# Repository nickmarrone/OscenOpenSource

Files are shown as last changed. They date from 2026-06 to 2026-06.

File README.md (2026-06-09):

# Oscen Open Source

Open source hardware designs for **Oscen Eurorack Modules**.

This repository contains the KiCad design files (schematics, PCB layouts, panels)
and manufacturing outputs (Gerbers, BOMs, pick-and-place files) for a selection of
Oscen's Eurorack modules, released for the community to study, build, and remix.

## Modules

| Module | Format | Description |
| --- | --- | --- |
| [Quad Passive Switch](QuadPassiveSwitch/) | 4HP, 3U | Four independent SPDT passive switches for manually routing signals — no power required. |

### Quad Passive Switch

A 4HP utility module with four independent **SPDT (single-pole, double-throw)**
toggle switches. Each section takes one input and routes it to one of two outputs
(or, run in reverse, selects between two inputs feeding a single output). The
signal path is entirely passive, so the module needs no power and adds no coloration
— useful for routing audio, CV, gates, clocks, or triggers.

See the [module README](QuadPassiveSwitch/README.md) for full details.

## Repository layout

Each module lives in its own directory and contains:

- `*.kicad_sch` — schematic
- `*.kicad_pcb` — main PCB layout
- `*_faceplate.kicad_pcb` — panel / faceplate layout
- `*.kicad_pro` / `*.kicad_prl` — KiCad project files
- `*.pdf` — rendered schematic
- `production/` — Gerbers, drill files, BOM, and pick-and-place outputs ready for fabrication

## Building these modules

1. Open the module's `.kicad_pro` in [KiCad](https://www.kicad.org/) (8.0 or newer) to view or edit the design.
2. To fabricate, send the Gerber `.zip` files in the module's `production/` directory
   to a PCB manufacturer, along with the BOM (`*_bom.csv`) and position
   (`*_positions.csv`) files if you want assembly.

## License

These designs are released as open source hardware. Unless otherwise noted in a
module's directory, you are free to build, modify, and share them. Please credit
**Oscen Modules**.

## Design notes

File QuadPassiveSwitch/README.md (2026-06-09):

# Quad Passive Switch

A 4HP, 3U Eurorack utility module with four independent **SPDT** (single-pole,
double-throw) passive switches. Each section manually routes one signal between two
destinations using a sub-mini toggle switch. The whole module is passive — it needs
**no power** and adds no buffering or coloration to the signal.

## Specifications

| | |
| --- | --- |
| Format | Eurorack, 3U |
| Width | 4HP (20 mm) |
| Panel height | 128.5 mm |
| Depth | Shallow (passive, no power header) |
| Power | None required |
| Switches | 4 × SPDT sub-mini toggle |
| Jacks | 12 × 3.5 mm mono switched |

## How it works

The module is divided into four identical sections, arranged top-left (TL),
top-right (TR), bottom-left (BL), and bottom-right (BR). Each section has:

- **IN** — signal input
- **OUT 1** — output selected when the toggle is in position 1
- **OUT 2** — output selected when the toggle is in position 2

The toggle switch connects **IN** to either **OUT 1** or **OUT 2**. Because the
path is just a mechanical contact, it works with any signal: audio, CV, gates,
clocks, or triggers.

### Reverse use (2-to-1)

Since the switch is passive and symmetrical, each section can be used in reverse:
patch two sources into **OUT 1** and **OUT 2**, and the toggle selects which one
appears at **IN**. In this mode **IN** becomes the output and the OUTs become inputs.

> Note: as with any passive multiple/switch, only patch a signal into one side of a
> given section at a time when using it in reverse, to avoid summing or back-feeding
> sources.

## Bill of materials

| Designators | Qty | Part | Footprint |
| --- | --- | --- | --- |
| J1–J12 | 12 | 3.5 mm mono switched jack (PJ398SM) | `EighthInch_PJ398SM` |
| SW1–SW4 | 4 | SPDT sub-mini toggle | `Switch_Toggle_SPDT_SubMini` |

See [`production/quad_passive_switch_gerbers_v1.0_bom.csv`](production/quad_passive_switch_gerbers_v1.0_bom.csv)
for the fabrication BOM.

## Files

- `quad_passive_switch.kicad_sch` — schematic
- `quad_passive_switch.kicad_pcb` — main PCB layout
- `quad_passive_switch_faceplate.kicad_pcb` — panel / faceplate layout
- `quad_passive_switch.pdf` — rendered schematic
- `quad_passive_switch.kicad_pro` — KiCad project
- `production/` — Gerbers (`*_gerbers_v1.0.zip`, `*_faceplate_gerbers_v1.0.zip`),
  drill/netlist, BOM, designators, and pick-and-place position files for v1.0

## Building it

1. Open `quad_passive_switch.kicad_pro` in [KiCad](https://www.kicad.org/) 8.0+ to
   inspect or modify the design.
2. To fabricate, send `production/quad_passive_switch_gerbers_v1.0.zip` (PCB) and
   `production/quad_passive_switch_faceplate_gerbers_v1.0.zip` (panel) to a PCB
   manufacturer.
3. Solder the 12 jacks and 4 toggle switches per the BOM. There are no other
   components — no resistors, ICs, or power connector.

## Revision

- **v1.0** — initial release.

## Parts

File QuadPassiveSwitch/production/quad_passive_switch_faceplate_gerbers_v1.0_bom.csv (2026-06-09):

Designator | Footprint | Quantity | Value | LCSC Part #
J1, J10, J11, J12, J2, J3, J4, J5, J6, J7, J8, J9 | EighthInch_PJ398SM | 12 | 3.5mm_Mono_Switched_SymSmall_0.05
SW1, SW2, SW3, SW4 | Switch_Toggle_SPDT_SubMini | 4 | SW_SPDT_MSM

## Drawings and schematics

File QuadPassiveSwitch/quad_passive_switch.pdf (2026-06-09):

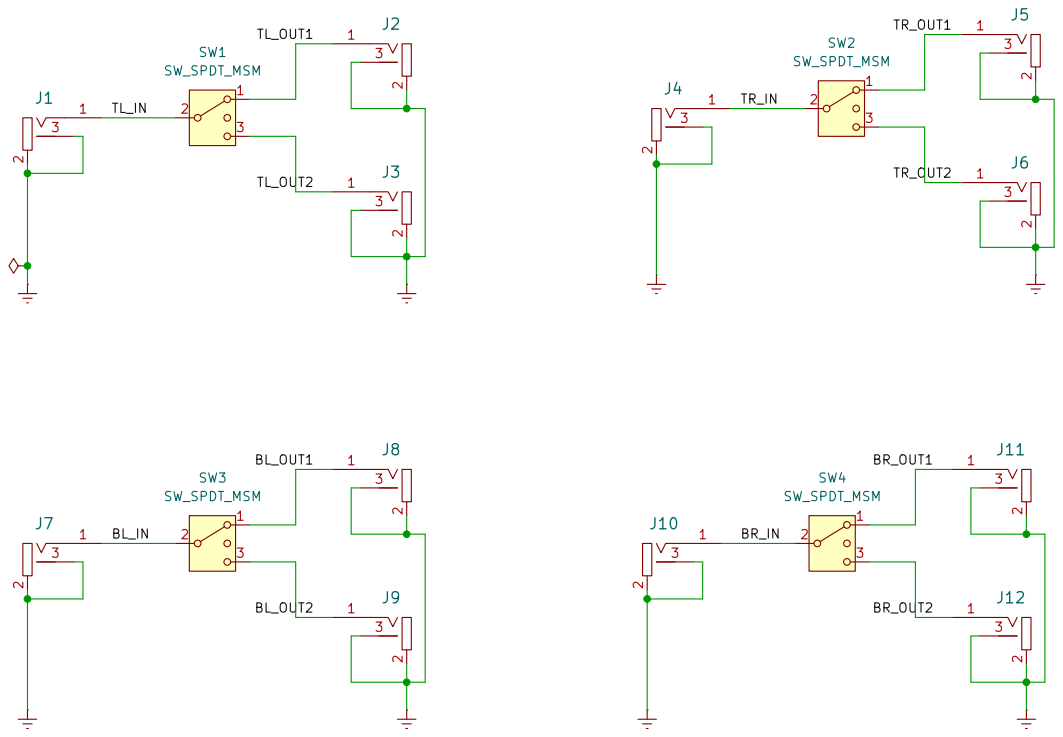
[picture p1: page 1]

Oscen Modules
Sheet: /
File: quad_passive_switch.kicad_sch
Title: Quad Passive Switch

Size: A4 | Rev: v1.0
KiCad E.D.A. 10.0.1 | Id: 1/1

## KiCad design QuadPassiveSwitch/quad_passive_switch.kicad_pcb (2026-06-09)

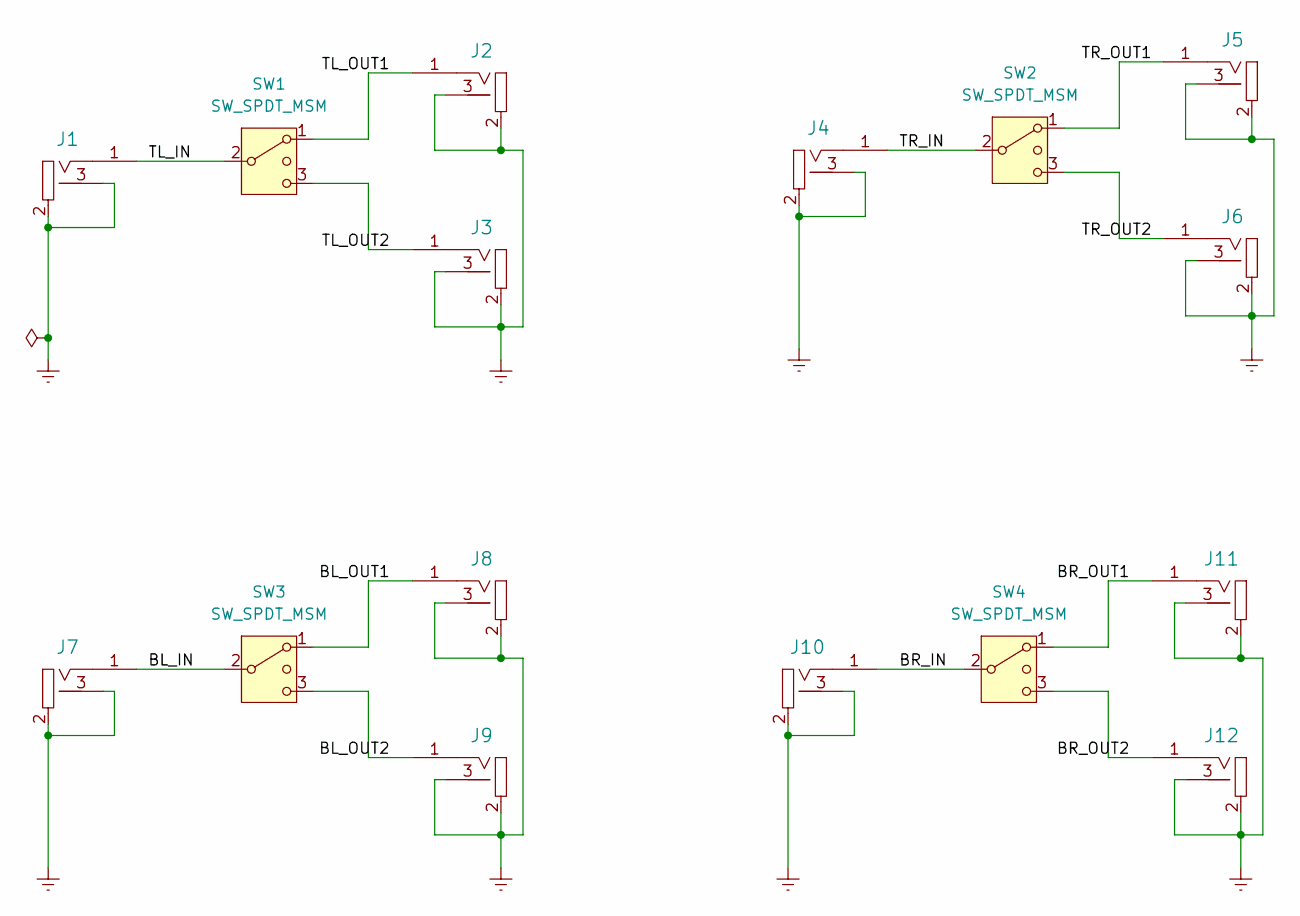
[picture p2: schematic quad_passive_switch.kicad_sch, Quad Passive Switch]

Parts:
J1, J2, J3, J4, J5, J6, J7, J8, J9, J10, J11, J12: 3.5mm_Mono_Switched_SymSmall_0.05; EighthInch_PJ398SM; Part Number WQP-WQP518MA
SW1, SW2, SW3, SW4: SW_SPDT_MSM; Switch_Toggle_SPDT_SubMini

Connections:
/BL_IN: J7.1 (SIG), SW3.2 (3)
/BL_OUT1: J8.1 (SIG), SW3.1
/BL_OUT2: J9.1 (SIG), SW3.3 (4)
/BR_IN: J10.1 (SIG), SW4.2 (3)
/BR_OUT1: J11.1 (SIG), SW4.1
/BR_OUT2: J12.1 (SIG), SW4.3 (4)
/TL_IN: J1.1 (SIG), SW1.2 (3)
/TL_OUT1: J2.1 (SIG), SW1.1
/TL_OUT2: J3.1 (SIG), SW1.3 (4)
/TR_IN: J4.1 (SIG), SW2.2 (3)
/TR_OUT1: J5.1 (SIG), SW2.1
/TR_OUT2: J6.1 (SIG), SW2.3 (4)
GNDREF: J1.2 (SHEILD), J1.3 (SW), J2.2 (SHEILD), J2.3 (SW), J3.2 (SHEILD), J3.3 (SW), J4.2 (SHEILD), J4.3 (SW), J5.2 (SHEILD), J5.3 (SW), J6.2 (SHEILD), J6.3 (SW), J7.2 (SHEILD), J7.3 (SW), J8.2 (SHEILD), J8.3 (SW), J9.2 (SHEILD), J9.3 (SW), J10.2 (SHEILD), J10.3 (SW), J11.2 (SHEILD), J11.3 (SW), J12.2 (SHEILD), J12.3 (SW)

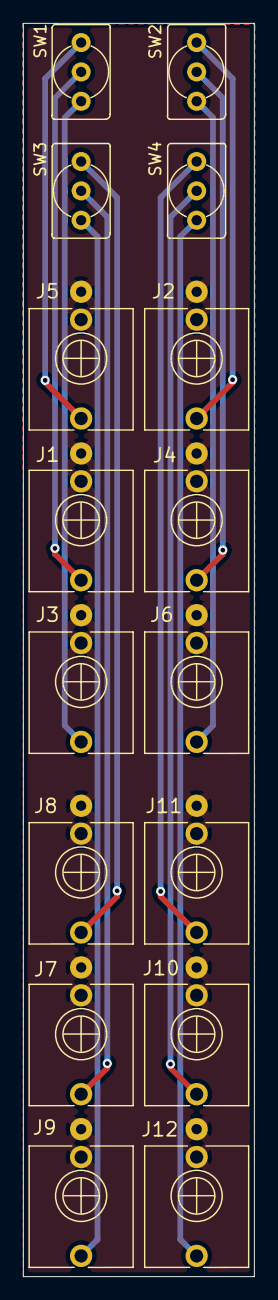
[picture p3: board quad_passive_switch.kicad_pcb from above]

Board: 2 copper layers, 20.0 x 108.5 mm, 16 parts (0 on the bottom side), 13 nets.

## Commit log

2026-06-09 Quad Passive Switch
    Add quad passive switch module. This takes four signals and allows the user to manually switch between two outs (or two ins) during a performance.
    [quad_passive_switch.kicad_pcb, quad_passive_switch.kicad_sch, quad_passive_switch_faceplate.kicad_pcb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]
2026-06-09 Add iBOM for quad passive switch
    [quad_passive_switch.kicad_pcb]
2026-06-09 Add version to quad passive switch PCB
    [quad_passive_switch.kicad_pcb, quad_passive_switch_faceplate.kicad_pcb, quad_passive_switch_faceplate_gerbers_v1.0_bom.csv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]
